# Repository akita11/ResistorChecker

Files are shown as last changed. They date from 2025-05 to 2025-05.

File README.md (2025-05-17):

# ResistorCheckerBase

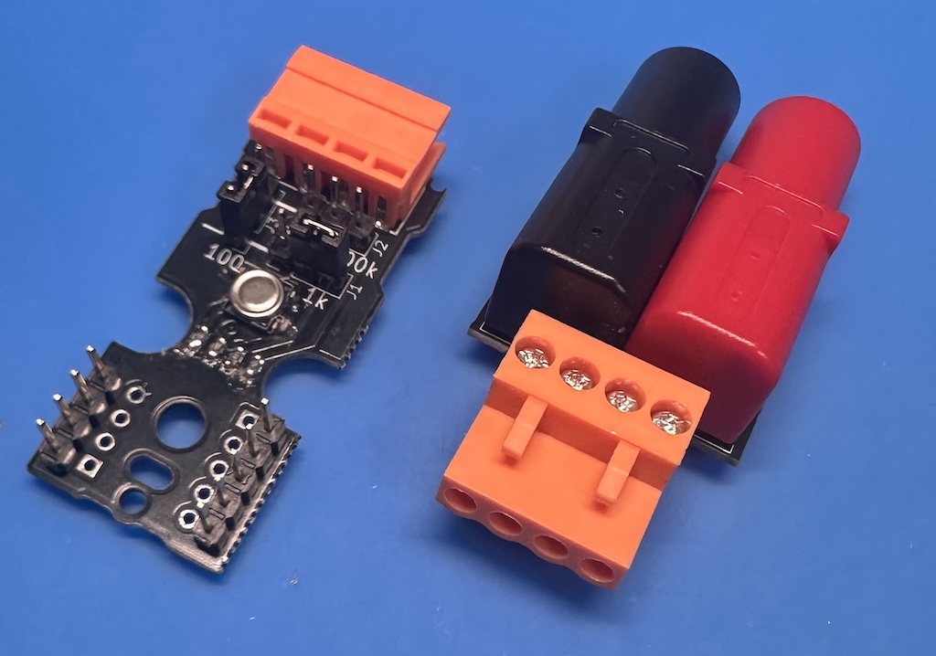
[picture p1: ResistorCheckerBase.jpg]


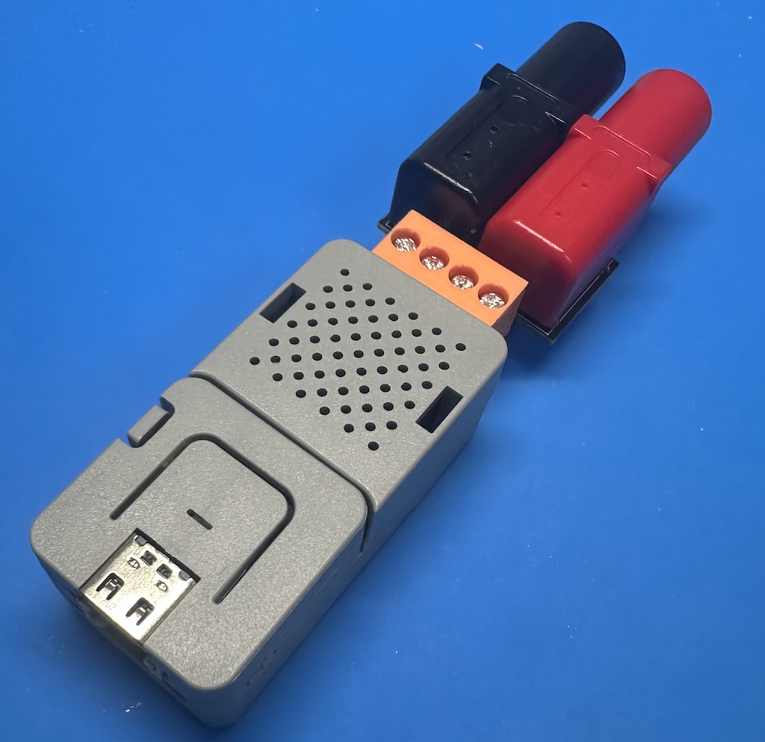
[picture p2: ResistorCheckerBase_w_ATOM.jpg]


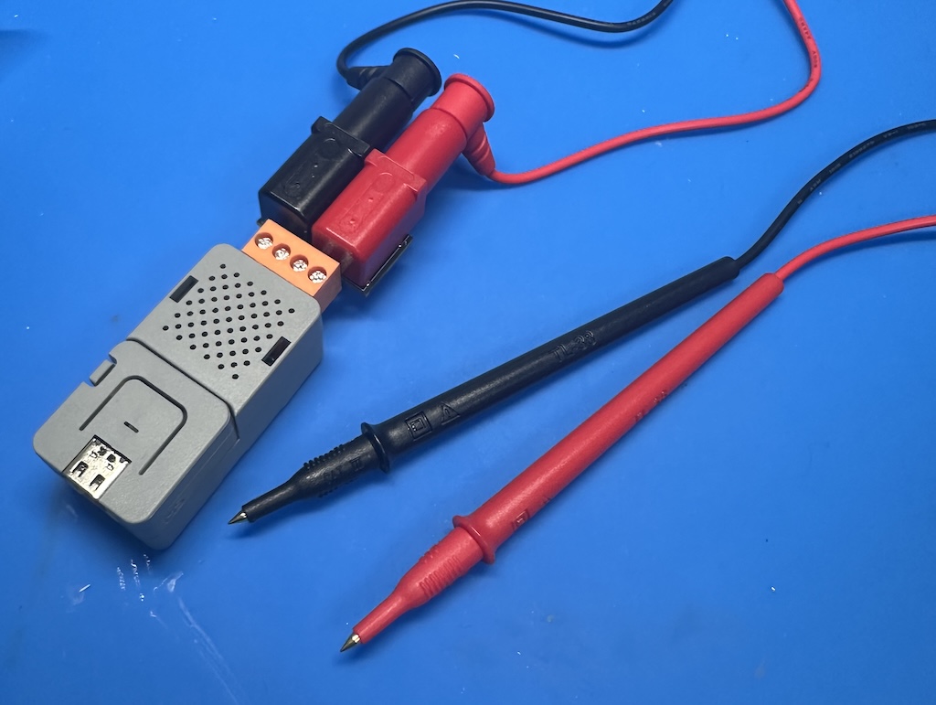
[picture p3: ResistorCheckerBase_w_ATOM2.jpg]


M5Stack ATOMシリーズを接続し、端子間の抵抗を計測できます。抵抗値が所定の範囲に収まっているかのチェックなどに使えます。抵抗測定レンジはジャンパピンで4段階に設定できます。また小型の圧電ブザーも搭載しています。

## 使い方

FW/内のプログラムを参考に、抵抗測定値に応じた動作を記述し、それをATOMシリーズに書き込んで本機に接続し、使用します。
例としてFW/には、抵抗測定値が抵抗測定レンジ（ジャンパピンで選択した参照抵抗値）の±10%以内に収まっていれば緑点灯（440Hzの音）、それ以下であれば赤点灯（880Hzの音）、それ以上であれば紫点灯（220Hzの音）となる動作を記述してあります。

## 抵抗測定レンジの設定

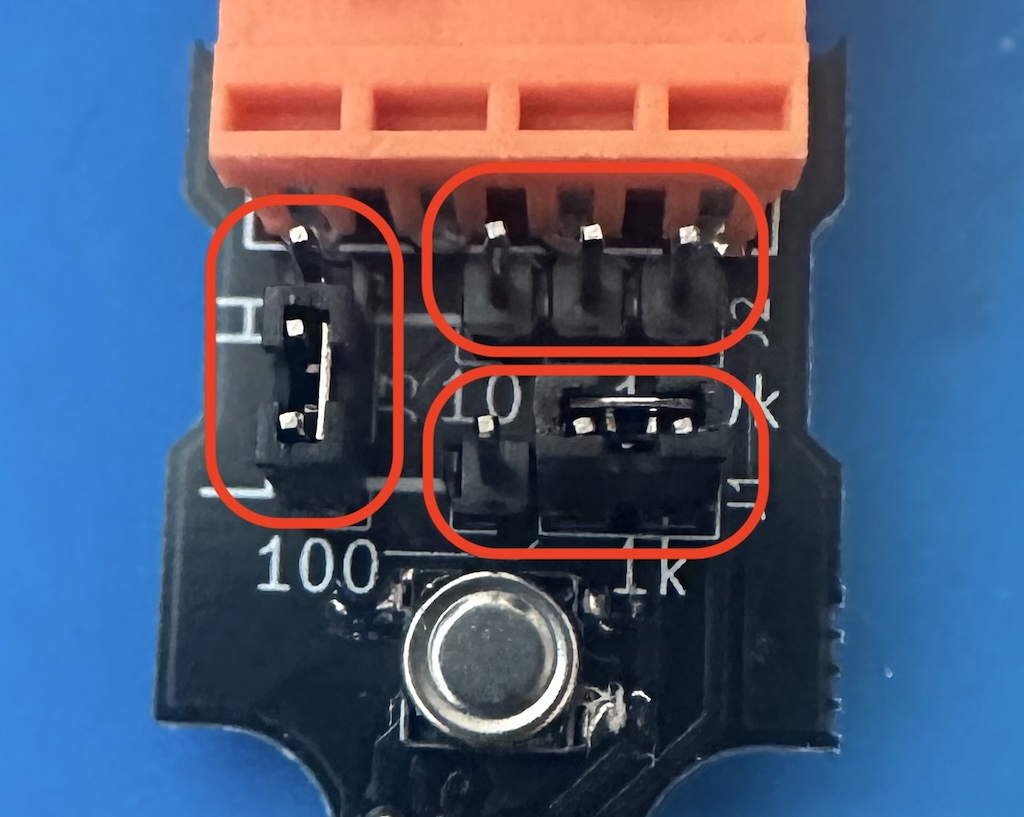
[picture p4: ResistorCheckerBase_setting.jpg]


測定対象の抵抗値にあわせて、抵抗測定レンジを設定することで測定精度を高めることができます。

- レンジ=L側 & 値=100側 : 100Ω
- レンジ=L側 & 値=1k側 : 1kΩ
- レンジ=H側 & 値=10k側 : 10kΩ
- レンジ=H側 & 値=100k側 : 100kΩ

## 技術的情報（測定原理）

抵抗値の測定は、本機の参照抵抗（100/1k/10k/100kからジャンパピンで選択）との分圧をATOMのアナログ入力ピンで計測しています。

測定対象の抵抗値をR、本機の参照抵抗値をRrefとすると、ATOMで測定される分圧Vmeasureは以下の式で求められます(VDD=3.3V)。この四季を使って、VmeasureからRを求めることができます。

Vmeasure = (Rref / (R + Rref) * VDD 

## Author

Junichi Akita (@akita11) / akita@ifdl.jp

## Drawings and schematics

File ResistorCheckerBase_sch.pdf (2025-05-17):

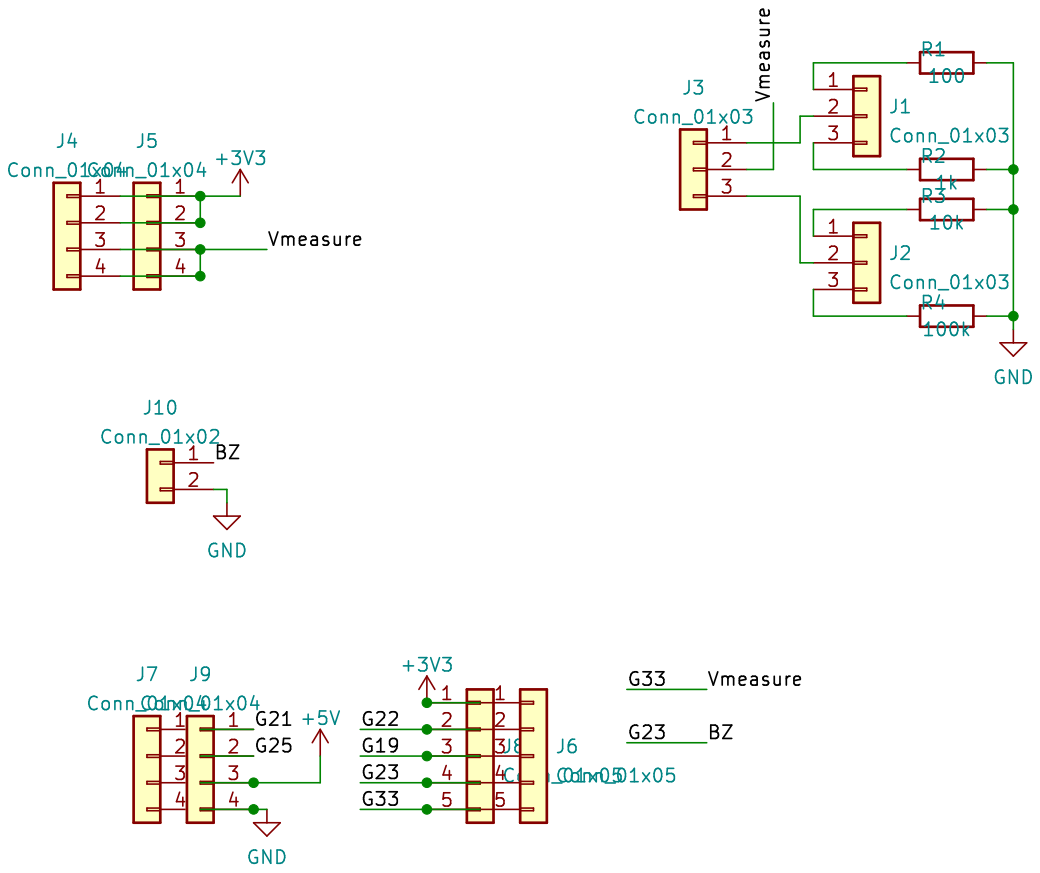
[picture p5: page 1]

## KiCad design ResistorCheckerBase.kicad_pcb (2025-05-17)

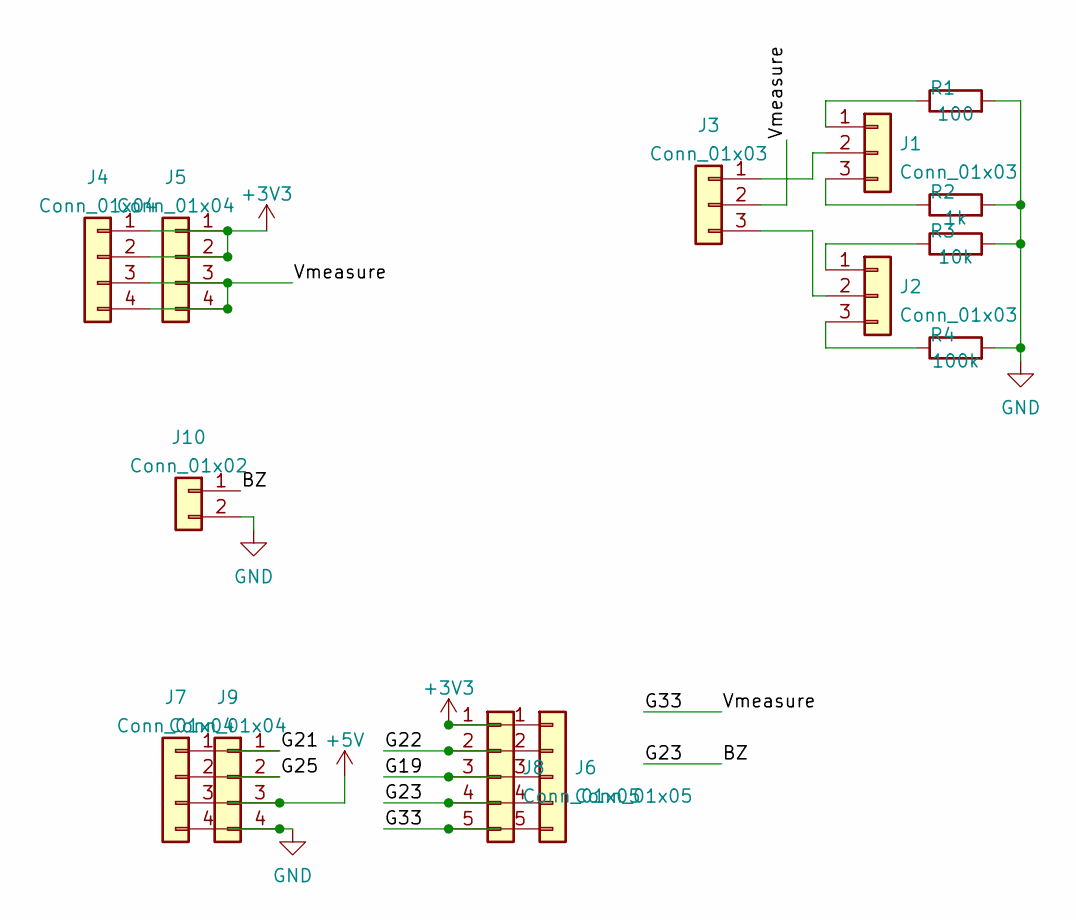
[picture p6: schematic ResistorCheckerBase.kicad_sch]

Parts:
J1, J2, J3: Conn_01x03; PinHeader_1x03_P2.54mm_Vertical
J4: Conn_01x04; CON_HT396R_4P_hole0.8sq
J5, J7, J9: Conn_01x04; PinHeader_1x04_P2.54mm_Vertical
J6, J8: Conn_01x05; PinHeader_1x05_P2.54mm_Vertical
J10: Conn_01x02; BZ_TSDZ5018
R1: 100; R_0603_1608Metric
R2: 1k; R_0603_1608Metric
R3: 10k; R_0603_1608Metric
R4: 100k; R_0603_1608Metric

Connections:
+3V3: J4.1, J4.2, J5.1, J5.2, J6.1, J8.1
+5V: J7.3, J9.3
/BZ: J6.4, J8.4, J10.1
/G19: J6.3, J8.3
/G21: J7.1, J9.1
/G22: J6.2, J8.2
/G25: J7.2, J9.2
/G33: J3.2, J4.3, J4.4, J5.3, J5.4, J6.5, J8.5
GND: J7.4, J9.4, J10.2, R1.2, R2.2, R3.2, R4.2
unnamed: J1.1, R1.1
unnamed: J1.2, J3.1
unnamed: J1.3, R2.1
unnamed: J2.1, R3.1
unnamed: J2.2, J3.3
unnamed: J2.3, R4.1

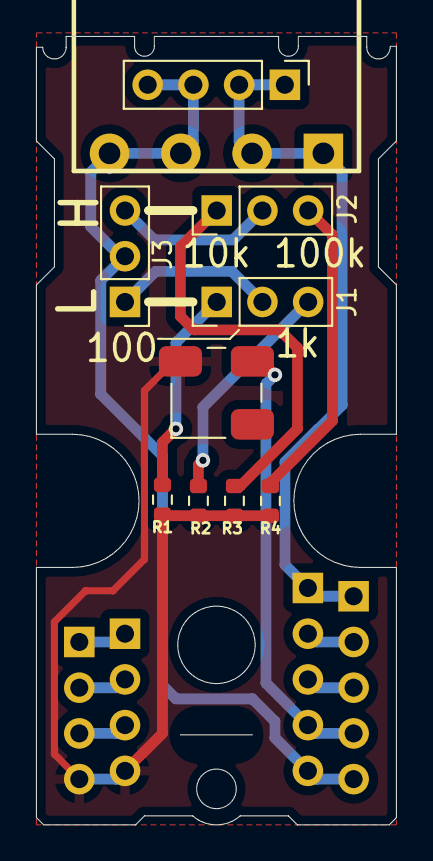
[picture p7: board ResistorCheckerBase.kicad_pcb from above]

Board: 2 copper layers, 20.0 x 43.8 mm, 14 parts (0 on the bottom side), 15 nets.

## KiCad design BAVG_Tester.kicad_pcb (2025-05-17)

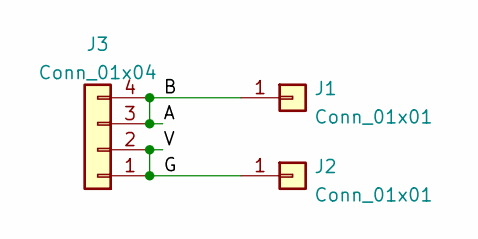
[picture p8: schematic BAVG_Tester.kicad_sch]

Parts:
J1, J2: Conn_01x01; CON_FCR7350
J3: Conn_01x04; CON_BAVG

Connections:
/B: J1.1, J3.3, J3.4
/G: J2.1, J3.1, J3.2

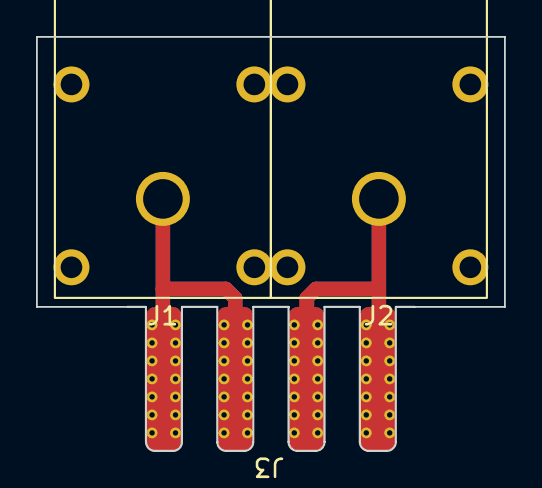
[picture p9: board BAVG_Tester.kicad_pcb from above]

Board: 2 copper layers, 26.0 x 23.0 mm, 3 parts (0 on the bottom side), 2 nets.

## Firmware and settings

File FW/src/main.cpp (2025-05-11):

#include <Arduino.h>
#include <M5Unified.h>
#include <FastLED.h>

#define NUM_LEDS 1
static CRGB leds[NUM_LEDS];

#if defined(ARDUINO_M5tack_ATOMS3)
// for ATOMS3 Lite
// G1/G2/V/D
#define PIN_ADC  1
#define PIN_BZ   2
#define PIN_LED  35
#elif defined(ARDUINO_M5Stack_ATOM)
// for ATOM Lite
// G1/G2/V/D
//#define PIN_ADC  32 // for Unit (Grove)
//#define PIN_BZ   26 // for Unit (Grove)
#define PIN_ADC  33 // for Base
#define PIN_BZ   23 // for Base
#define PIN_LED  27
#endif

void showLED(int r, int g, int b) {
	leds[0] = CRGB(r, g, b);
	FastLED.show();
}

// read voltage [mV]
float readVoltage(int samples = 10) 
{
	long sum = 0;
	for (int i = 0; i < samples; ++i) {
//		sum += analogRead(PIN_ADC);
		sum += analogReadMilliVolts(PIN_ADC);
}
//	return sum / (float)samples * 3300 / 4095.0;
	return sum / (float)samples; // [mV]
}

float calcResistance(float V, float Rref) {
	if (V == 0) return(1e9); // disconnected, R=inf
	return Rref * (3300.0 - V) / V;
}

uint8_t range = 0;

float Rstd = 1000; // [ohm]
float Rmin = Rstd * 0.9; // -10%
float Rmax = Rstd * 1.1; // +10%
float Rdisconnect = Rstd * 10;

void setTone(int freq) {
	if (freq > 0) {
		ledcWriteTone(0, freq);
	} else {
		ledcWrite(0, 0);
	}
}

void setup() {
	auto cfg = M5.config();
	M5.begin(cfg);
	FastLED.addLeds<WS2811, PIN_LED, GRB>(leds, NUM_LEDS);
	FastLED.setBrightness(30);
	showLED(0, 0, 10);  // blue (idle)
  ledcSetup(0, 24000, 11);
	ledcWrite(0, 0);
  ledcAttachPin(PIN_BZ, 0);
}

uint8_t st = 0, st0 = 0;
uint8_t cnt = 0;

void loop() {
/*
	M5.update();
	if (M5.BtnA.wasClicked()) {
		range = (range + 1) % 4;
		switch(range) {
			case 0 : setTone(220); printf("220Hz\n"); break;
			case 1 : setTone(440); printf("440Hz\n"); break;
			case 2 : setTone(880); printf("880Hz\n"); break;
			case 3 : setTone(0); printf("stop\n"); break;
		}
		delay(500);
	}
*/
	float V = readVoltage();
	float R = calcResistance(V, Rstd);
	if (R > Rmin && R < Rmax){
		// OK
		st = 1;
	}
	else if (R < Rmin) {
		// R is too small
		st = 2;
	}
	else if (R > Rmax && R < Rdisconnect) {
		// R is too large
		st = 3;
	}
	else {
		// disconnected / idle
		st = 0;
	}

	printf("%d / %f / %f\n", st, V, R);

	if (st != st0){
		switch (st){
			case 0: setTone(0);   showLED( 0,  0, 10); break; // blue
			case 1: setTone(440); showLED( 0, 40,  0); break; // green
			case 2: setTone(880); showLED(40,  0,  0); break; // red
			case 3: setTone(220); showLED(20,  0, 20); break; // purple
		}
		st0 = st;
	}
}
